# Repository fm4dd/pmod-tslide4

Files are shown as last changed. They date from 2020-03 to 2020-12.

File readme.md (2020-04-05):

## TSLIDE4 PMOD

### Description

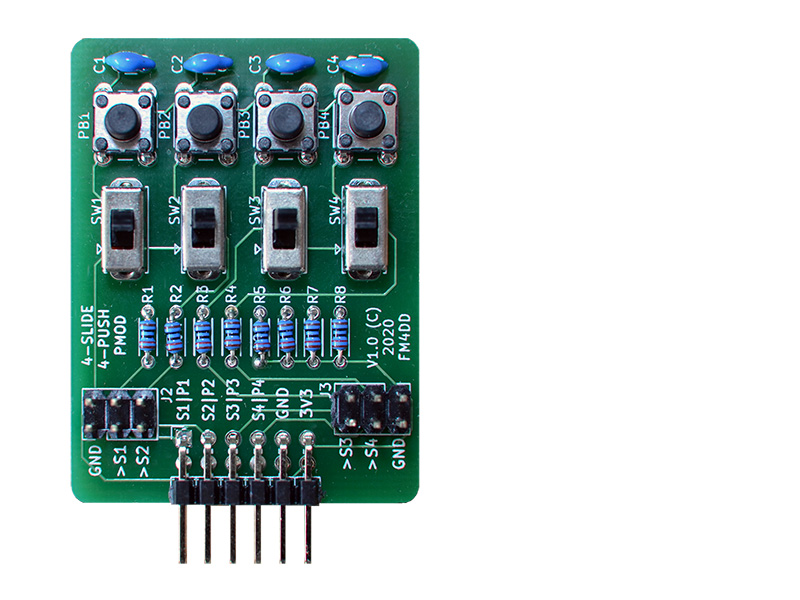
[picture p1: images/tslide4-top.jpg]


This PMOD provides four slide switch and four touch-button inputs to FPGA designs via a single double-row PMOD. The four slide switches can be individually disabled through two sets of jumpers (J2 and J3, signal S1-S4). This can free up IO pins on the IceBreaker v1.0 board if only push-buttons are needed. The Icebreaker has only 24 multi-purpose IO, which creates a challenge for advanced designs. Push buttons use inverse logic, the button press creates a "LOW" signal.

http://fpga.fm4dd.com/

### Schematic

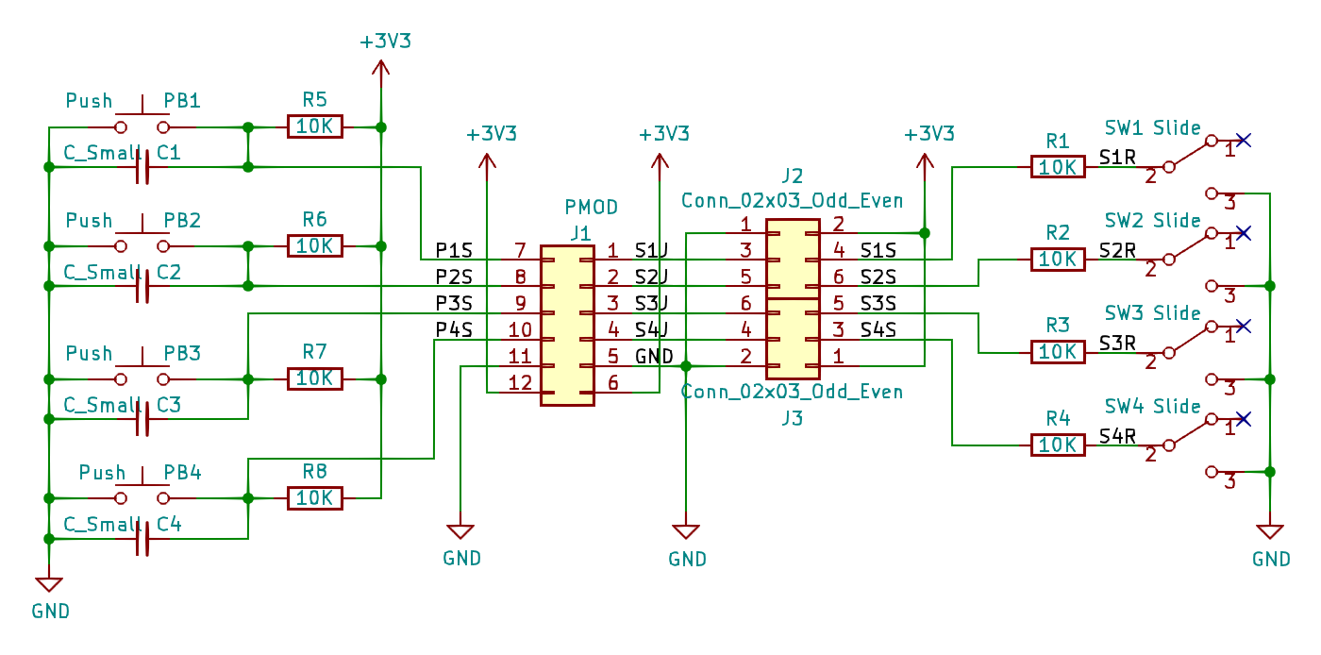
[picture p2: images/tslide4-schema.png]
TSLIDE4 PMOD Schematics


### PCB Gerber

[20200301 TSLIDE4 Gerber v1.1](20200301-tslide4-gerber-v11.zip)

### Pin Assignments

#### IceBreaker v1.0

TSLIDE4 PMOD, connected to a Icebreaker v1.0 board

 J1# |  Label | Description   | PMOD1A| PMOD1B | PMOD2
-----|--------|---------------|-------|--------|-------
1    |  SW1   | Slide Switch1 | 4     | 43     | 27
2    |  SW2   | Slide Switch2 | 2     | 38     | 25
3    |  SW3   | Slide Switch3 | 47    | 34     | 21
4    |  SW4   | Slide Switch4 | 45    | 31     | 19
7    |  PB1   | Push Button1  | 3     | 42     | 26
8    |  PB2   | Push Button2  | 48    | 36     | 23
9    |  PB3   | Push Button3  | 46    | 32     | 20
10   |  PB4   | Push Button4  | 44    | 28     | 18

#### DE0-Nano-SoC

The connection to Intels DE0-Nano-SoC is made through the pmod2nano adapter.

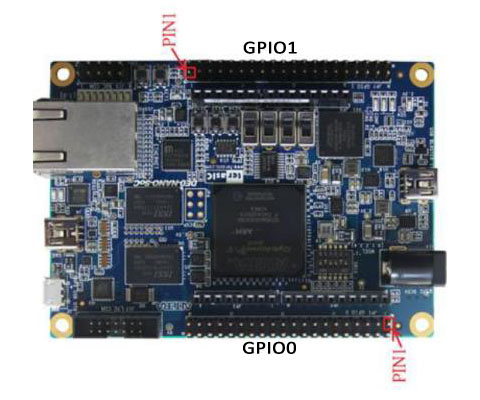
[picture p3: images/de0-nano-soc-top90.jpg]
DE0-Nano-SoC


 J1# |  Label | Description   | GPIO0A | GPIO0B | GPIO1A | GPIO1B
-----|--------|---------------|--------|--------|--------|--------
1    |  PB1   | Push Button1  | PIN_W12| PIN_AF4|PIN_AA15| PIN_AH23
2    |  PB2   | Push Button2  | PIN_Y8 | PIN_AF5|PIN_AG26| PIN_AE19
3    |  PB3   | Push Button3  | PIN_W8 | PIN_T13|PIN_AF23| PIN_AD19
4    |  PB4   | Push Button4  | PIN_Y5 | PIN_AE7|PIN_AF21| PIN_AE24
7    |  SW1   | Slide Switch1 | PIN_AF8| PIN_AG6|PIN_AH27| PIN_AG23
8    |  SW2   | Slide Switch2 | PIN_AB4| PIN_AE4|PIN_AH24| PIN_AF18
9    |  SW3   | Slide Switch3 | PIN_Y4 | PIN_T11|PIN_AE22| PIN_AE20
10   |  SW4   | Slide Switch4 | PIN_U11| PIN_AF6|PIN_AG20| PIN_AD20

### Example Code

#### Verilog

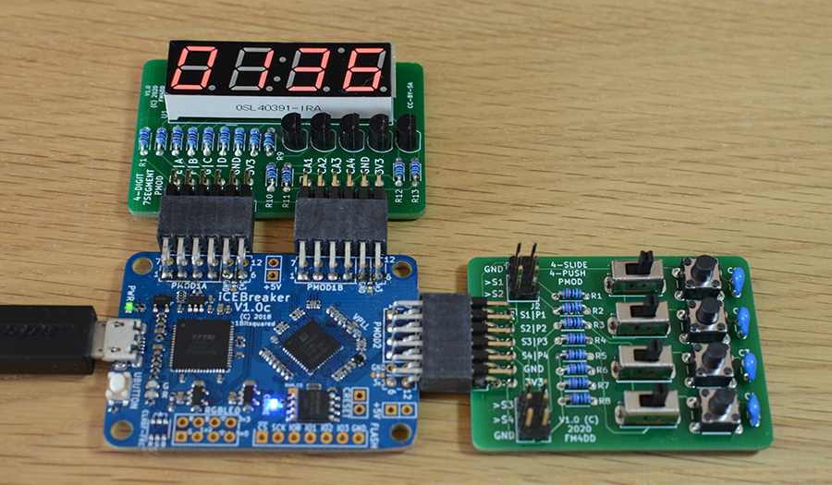
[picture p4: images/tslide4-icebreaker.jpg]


Below is a test program to verify the correct function of the TSLIDE4 PMOD.
The programm assumes an additional 8LED2 PMOD connected to show LED output.

The design links the four slide switches with LED D1-D4 in green color,
and the four push button switches with LED D5-D8 in red color.

Operating the switches simply turns the corresponding LED on or off.

Verilog test program pmod_tslide4_1.v (top-level):
```
// -------------------------------------------------------
// This program tests HW pin assignment for TSlide4 pmods
// -------------------------------------------------------
module pmod_tslide4_1 (
  input SW1,
  input SW2,
  input SW3,
  input SW4,
  input PB1,
  input PB2,
  input PB3,
  input PB4,
  output reg [0:7] pmodledg,
  output reg [0:7] pmodledr
);

always
begin
  // pmodledg[0] = 1'b1;  // light up D1
  pmodledg[0] = SW1;
  pmodledg[1] = SW2;
  pmodledg[2] = SW3;
  pmodledg[3] = SW4;
  pmodledr[7] = ~PB1;
  pmodledr[6] = ~PB2;
  pmodledr[5] = ~PB3;
  pmodledr[4] = ~PB4;
end
endmodule
```
#### VHDL

This is Verilog test program pmod_tslide4_1.v converted to VHDL as pmod_tslide4_2.vhd

```
-- -------------------------------------------------------
-- This program tests HW pin assignment for TSlide4 pmods
-- -------------------------------------------------------
library ieee;
use ieee.std_logic_1164.all;
use ieee.numeric_std.all;

entity pmod_tslide4_2 is
port ( SW1: in STD_LOGIC := '1';
       SW2: in STD_LOGIC := '1';
       SW3: in STD_LOGIC := '1';
       SW4: in STD_LOGIC := '1';
       PB1: in STD_LOGIC := '1';
       PB2: in STD_LOGIC := '1';
       PB3: in STD_LOGIC := '1';
       PB4: in STD_LOGIC := '1';
  pmodledg: out STD_LOGIC_VECTOR(0 to 7) := "00000000";
  pmodledr: out STD_LOGIC_VECTOR(0 to 7) := "00000000"
);
end pmod_tslide4_2;

architecture arch of pmod_tslide4_2 is
begin
  -- pmodledg(0) <= '1';  // light up D1
  pmodledg(0) <= SW1;
  pmodledg(1) <= SW2;
  pmodledg(2) <= SW3;
  pmodledg(3) <= SW4;

  pmodledr(4) <= NOT PB1;
  pmodledr(5) <= NOT PB2;
  pmodledr(6) <= NOT PB3;
  pmodledr(7) <= NOT PB4;
end arch;
```
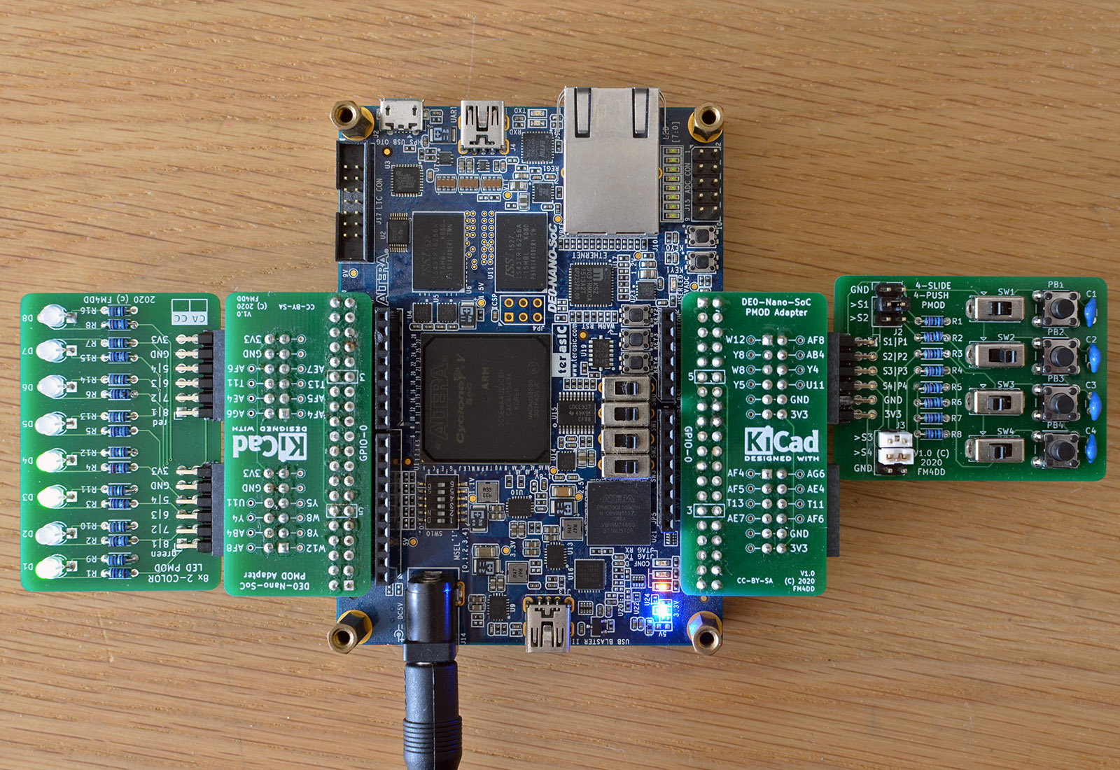
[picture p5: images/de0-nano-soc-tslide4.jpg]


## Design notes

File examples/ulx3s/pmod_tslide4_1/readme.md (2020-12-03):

# Design Notes

This is a test program to verify the correct function of the tslide4 PMOD.
It assumes a TSlide4 PMOD connected to a ULX3S J1 connector, and a
8LED2 PMOD connected to the J2 connector.

The design links the four slide switches with LED D1-D4 in green color,
and the four push button switches with LED D5-D8 in red color.

Operating the switches simply turns the corresponding LED on or off.

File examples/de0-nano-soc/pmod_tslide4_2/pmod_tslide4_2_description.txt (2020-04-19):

This program is demonstrating the function of the TSlide4 PMOD under VHDL.  It assumes a TSlide4 PMOD connected to IceBreaker PMOD2 connector, and a 8LED2 PMOD connected to PMOD1A and PMOD1B connectors. The design links the four slide switches with LED D1-D4 in green color,
and the four push button switches with LED D5-D8 in red color. Operating the switches simply turns the corresponding LED on or off.

The functionality has been converted from the Verilog program pmod_tslide4_1.v, tested on a Icebreaker v1.0 board, using the Linux open source workflow (yosys, nextpnr, and icestorm). Without an open source VHDL workflow, I am testing VHDL on a DE0-Nano-SoC board with Quartus Prime Version 17.1 Lite Edition on Windows.

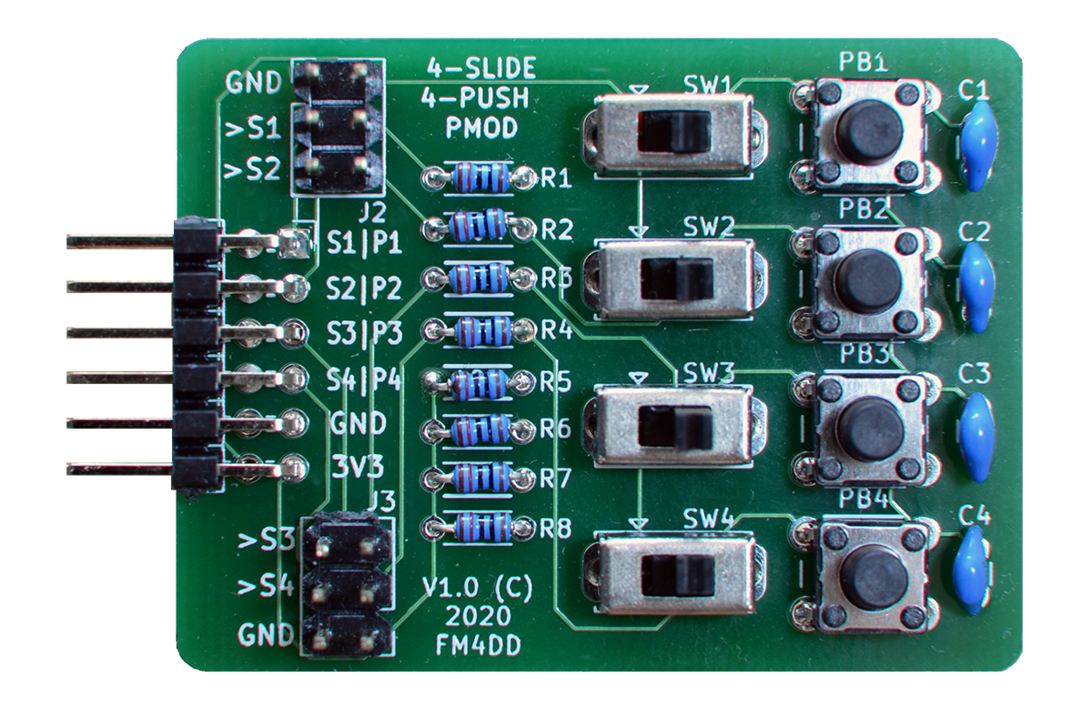
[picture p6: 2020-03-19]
images/tslide4-pmod-top-med.png

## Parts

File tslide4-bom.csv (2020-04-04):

Manufacturer Part Number | Manufacturer | Digi-Key Part Number | Reference | Quantity | Description
RNMF14FTC10K0 | Stackpole Electronics Inc | S10KCACT-ND | R1-8 | 8 | RES 10 KOHM 1/4W 1% AXIAL
K105Z20Y5VF5TL2 | Vishay BC Components | BC1162CT-ND | C1-4 | 4 | CAP CER 1UF 50V Y5V RADIAL
OS102011MS2QN1 | C&K | CKN9565-ND | SW1-4 | 4 | SWITCH SLIDE SPDT 100MA 12V
3-1825910-5 | TE Connectivity ALCOSWITCH | 450-1644-ND | PB1-4 | 4 | SWITCH TACTILE SPST-NO 0.05A 24V
PEC20DBAN | Sullins Connector Solutions | S2112E-20-ND | J1 | 1 | CONN HEADER R/A 40POS 2.54MM cut to size
68786-102LF | Amphenol ICC (FCI) | 609-3121-ND | Jumper J2,J3 | 4 | CONN SHUNT 2POS .100 LOPRO GOLD
67997-206HLF | Amphenol ICC (FCI) | 609-3234-ND | J2,J3 | 2 | CONN HEADER VERT 6POS 2.54MM

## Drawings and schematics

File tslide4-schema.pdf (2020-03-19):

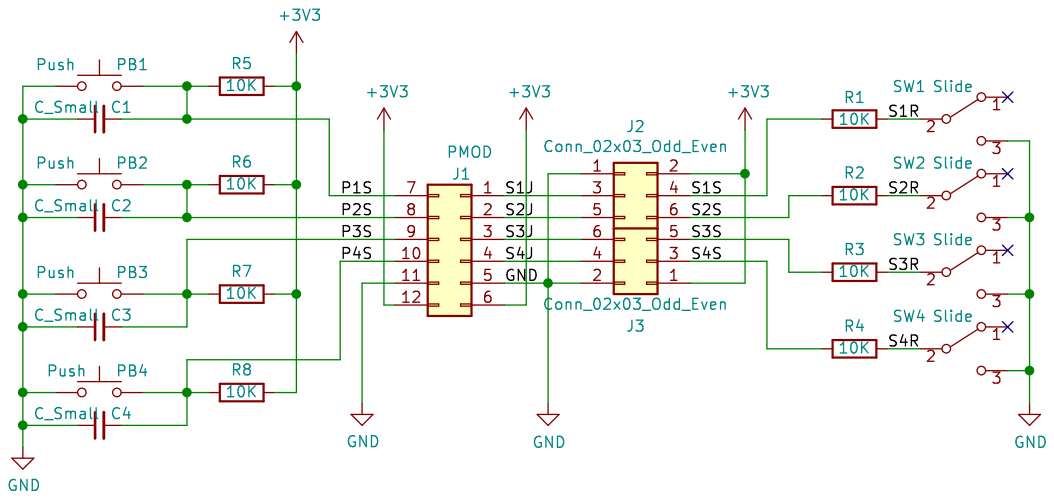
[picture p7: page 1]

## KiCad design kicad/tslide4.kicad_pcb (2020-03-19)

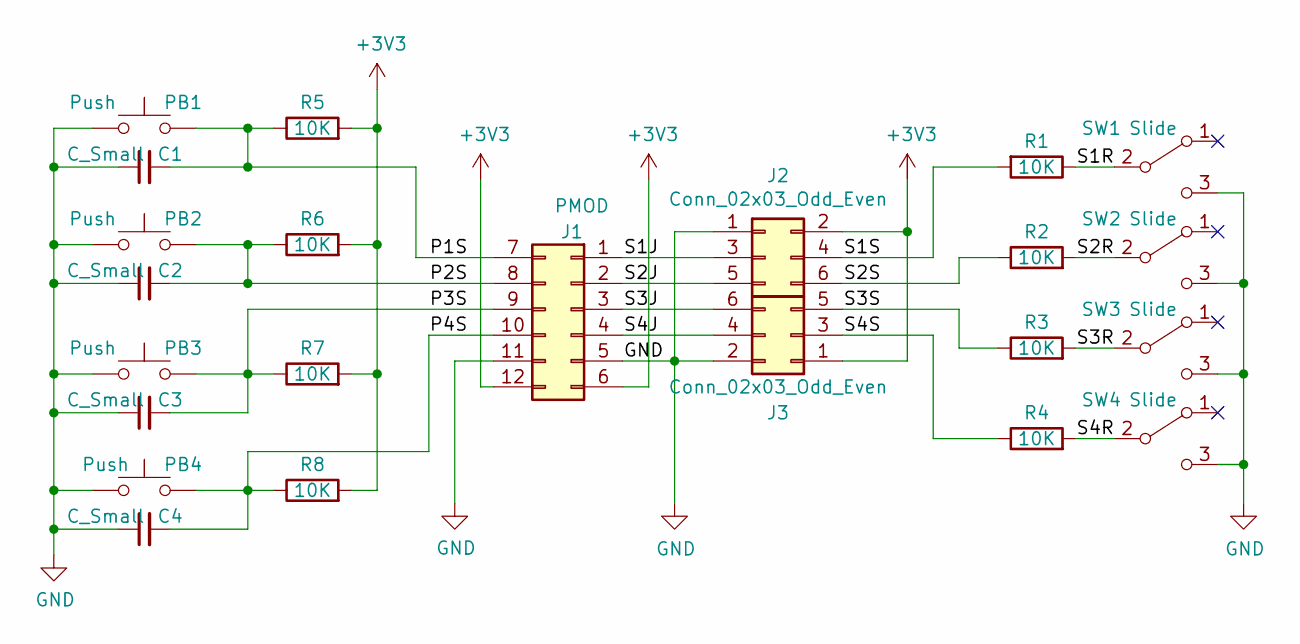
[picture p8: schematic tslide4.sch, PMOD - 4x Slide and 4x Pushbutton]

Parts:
C1, C2, C3, C4: C_Small; C_Disc_D3.0mm_W1.6mm_P2.50mm
J1: PMOD; PMODHeader_2x06_P2.54mm_Horizontal
J2, J3: Conn_02x03_Odd_Even; PinHeader_2x03_P2.54mm_Vertical
PB1, PB2, PB3, PB4: Push; SW_PUSH_6mm
R1, R2, R3, R4, R5, R6, R7, R8: 10K; R_Axial_DIN0204_L3.6mm_D1.6mm_P5.08mm_Horizontal
SW1, SW2, SW3, SW4: Slide; SlideSW_SS12-D01

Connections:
+3V3: J1.6, J1.12, J2.2, J3.1, R5.2, R6.2, R7.2, R8.2
/P1S: C1.2, J1.7, PB1.2, R5.1
/P2S: C2.2, J1.8, PB2.2, R6.1
/P3S: C3.2, J1.9, PB3.2, R7.1
/P4S: C4.2, J1.10, PB4.2, R8.1
/S1J: J1.1, J2.3
/S1R: R1.1, SW1.2 (B)
/S1S: J2.4, R1.2
/S2J: J1.2, J2.5
/S2R: R2.2, SW2.2 (B)
/S2S: J2.6, R2.1
/S3J: J1.3, J3.6
/S3R: R3.2, SW3.2 (B)
/S3S: J3.5, R3.1
/S4J: J1.4, J3.4
/S4R: R4.2, SW4.2 (B)
/S4S: J3.3, R4.1
GND: C1.1, C2.1, C3.1, C4.1, J1.5, J1.11, J2.1, J3.2, PB1.1, PB2.1, PB3.1, PB4.1, SW1.3 (C), SW2.3 (C), SW3.3 (C), SW4.3 (C)

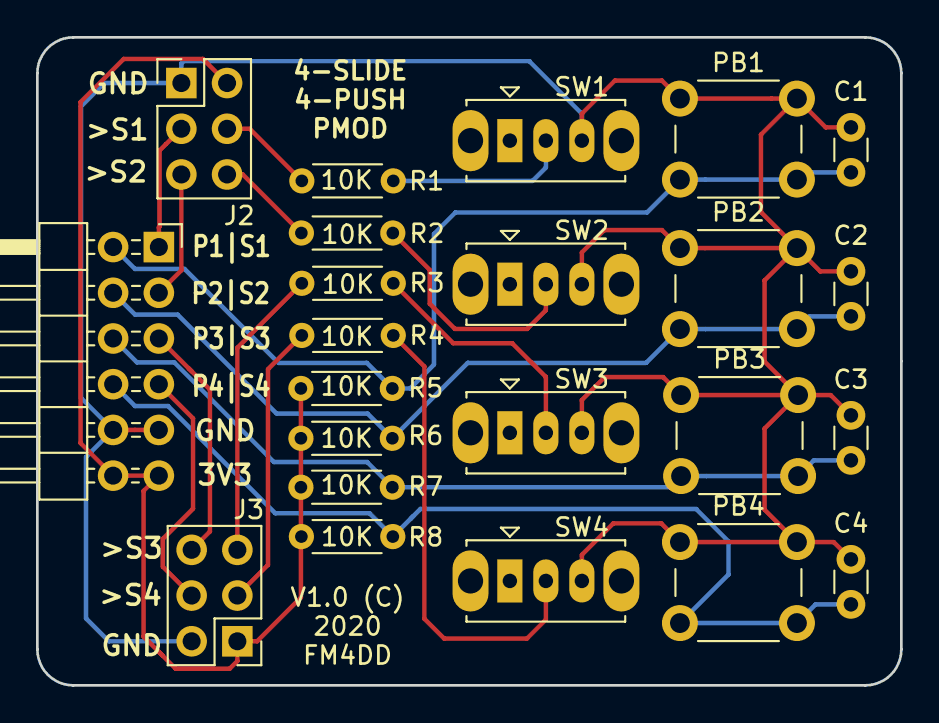
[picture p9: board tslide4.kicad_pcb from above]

Board: 2 copper layers, 48.0 x 36.0 mm, 23 parts (0 on the bottom side), 18 nets.

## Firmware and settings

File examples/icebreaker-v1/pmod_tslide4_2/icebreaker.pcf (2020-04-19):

# 12 MHz clock
set_io -nowarn clk        35

# RS232
set_io -nowarn RX          6
set_io -nowarn TX          9

# LEDs and Button
set_io -nowarn BTN_N      10
set_io -nowarn LEDR_N     11
set_io -nowarn LEDG_N     37

# RGB LED Driver
set_io -nowarn LED_RED_N  39
set_io -nowarn LED_GRN_N  40
set_io -nowarn LED_BLU_N  41

# SPI Flash
set_io -nowarn FLASH_SCK  15
set_io -nowarn FLASH_SSB  16
set_io -nowarn FLASH_IO0  14
set_io -nowarn FLASH_IO1  17
set_io -nowarn FLASH_IO2  12
set_io -nowarn FLASH_IO3  13

# PMOD 1A
#set_io -nowarn P1A1        4
#set_io -nowarn P1A2        2
#set_io -nowarn P1A3       47
#set_io -nowarn P1A4       45
#set_io -nowarn P1A7        3
#set_io -nowarn P1A8       48
#set_io -nowarn P1A9       46
#set_io -nowarn P1A10      44
set_io -nowarn pmodledg[0]  4
set_io -nowarn pmodledg[1]  2
set_io -nowarn pmodledg[2] 47
set_io -nowarn pmodledg[3] 45
set_io -nowarn pmodledg[4]  3
set_io -nowarn pmodledg[5] 48
set_io -nowarn pmodledg[6] 46
set_io -nowarn pmodledg[7] 44

# PMOD 1B
#set_io -nowarn P1B1       43
#set_io -nowarn P1B2       38
#set_io -nowarn P1B3       34
#set_io -nowarn P1B4       31
#set_io -nowarn P1B7       42
#set_io -nowarn P1B8       36
#set_io -nowarn P1B9       32
#set_io -nowarn P1B10      28
set_io -nowarn pmodledr[0] 43
set_io -nowarn pmodledr[1] 38
set_io -nowarn pmodledr[2] 34
set_io -nowarn pmodledr[3] 31
set_io -nowarn pmodledr[4] 42
set_io -nowarn pmodledr[5] 36
set_io -nowarn pmodledr[6] 32
set_io -nowarn pmodledr[7] 28

# PMOD 2
#set_io -nowarn P2_1       27
#set_io -nowarn P2_2       25
#set_io -nowarn P2_3       21
#set_io -nowarn P2_4       19
#set_io -nowarn P2_7       26
#set_io -nowarn P2_8       23
#set_io -nowarn P2_9       20
#set_io -nowarn P2_10      18

# PMOD 2 with FM4DD TSlide4 PMOD
set_io -nowarn SW1        27
set_io -nowarn SW2        25
set_io -nowarn SW3        21
set_io -nowarn SW4        19
set_io -nowarn PB1        26
set_io -nowarn PB2        23
set_io -nowarn PB3        20
set_io -nowarn PB4        18

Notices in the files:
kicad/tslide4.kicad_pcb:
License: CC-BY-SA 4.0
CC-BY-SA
